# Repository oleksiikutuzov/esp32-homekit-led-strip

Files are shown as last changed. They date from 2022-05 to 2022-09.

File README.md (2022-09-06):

# esp32-homekit-led-strip
Native Apple HomeKit via an ESP32 for the NeoPixel LED Strip or any 5V LED Strip



Software is based on [HomeSpan](https://github.com/HomeSpan/HomeSpan) library. Supports RGB or RGBW Neopixel strips and optionally can act like a switch for any 5V electronics (Switch accessory in HomeKit can be shown as a Bulb, Socket or Fan).

_As usual, don't expect any warranties. I am just a hobbyist, not a professional. It works for me, but you take your own risk using it. I am not liable for any damage to your devices._

## Hardware

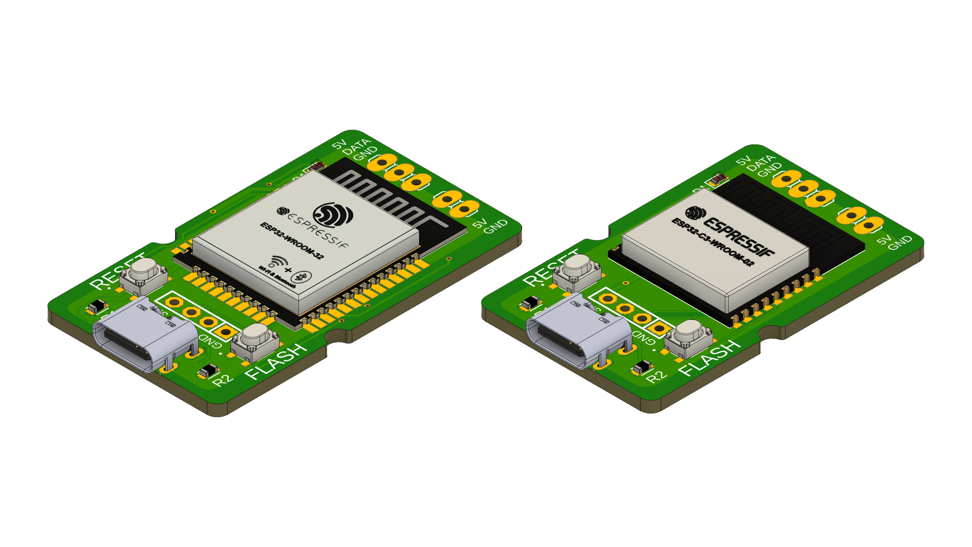
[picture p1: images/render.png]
render


Custom PCB is designed for the project. Currently for regular ESP32 board, however there are plans to do for ESP32-C3, which has smaller footprint.

## HomeKit functions

Device has three modes, which can be switched via the Eve app. As they are custim characteristics, they are not visible in the Home app:
* Manual Control (manually set one single color)
* Rainbow (the whole strip is changing colors)
* Color Wheel (strip has different colors "running" along)

Also in the Eve app you can set the number of LEDs in your strip (default is 90). After changing this characteristic, you need to restart the controller for changes to take effect. 

Characteristics values are saved to NVS, so they will be restored if device looses power. 

At the moment you can enable the Switch device in the sketch by defining the `RELAY` variable, but in the future this will implemented via custom characteristic as well to be able to enable it when device is running.

## Software

Here you can see, which pins are used and pre-defined in the firmware:
```c++
 *                ESP-WROOM-32 Utilized pins
 *              ╔═════════════════════════════╗
 *              ║┌─┬─┐  ┌──┐  ┌─┐             ║
 *              ║│ | └──┘  └──┘ |             ║
 *              ║│ |            |             ║
 *              ╠═════════════════════════════╣
 *          +++ ║GND                       GND║ +++
 *          +++ ║3.3V                     IO23║ USED_FOR_NOTHING
 *              ║                         IO22║
 *              ║IO36                      IO1║ TX
 *              ║IO39                      IO3║ RX
 *              ║IO34                     IO21║
 *              ║IO35                         ║ NC
 *      RED_LED ║IO32                     IO19║
 *              ║IO33                     IO18║ RELAY
 *              ║IO25                      IO5║
 *              ║IO26                     IO17║ NEOPIXEL
 *              ║IO27                     IO16║
 *              ║IO14                      IO4║
 *              ║IO12                      IO0║ +++, BUTTON
 *              ╚═════════════════════════════╝
```

The firmware can be built and flashed using the Arduino IDE.

For this, you will need to add ESP32 support to it.

Furthermore, you will also need to install the following libraries using the Library Manager:

* HomeSpan

And some libraries manually:

1. Go to this GitHub repo and download it as a ZIP - [AsyncElegantOTA](https://github.com/ayushsharma82/AsyncElegantOTA)
2. In Arduino IDE select "Sketch" -> "Include Library" and "Add .ZIP Library..." and select downloaded ZIP
3. Do previous steps to the following libraries: 
   * [ESPAsyncWebServer](https://github.com/me-no-dev/ESPAsyncWebServer)
   * [AsyncTCP](https://github.com/me-no-dev/AsyncTCP)
4. Download and open this repository in Arduino IDE (or VSCode with Arduino extension)
5. Set the upload speed to 115200
6. Build, flash, and you're done

Instead of Arduino IDE OTA, the webserver update was implemented. You can flash binary at `http://[DEVICE IP]/update`.
There is a reboot link. Opening `http://[DEVICE IP]/reboot` will force the device to reboot. 

The device can also be controlled by the FLASH button on the board. More on [HomeSpan docs](https://github.com/HomeSpan/HomeSpan/blob/master/docs/UserGuide.md)

## Connect to HomeKit

1. Plug your LED Controller to power.
2. Press the FLASH button until the LED starts blinking rapidly and release it. Now it is in the configuration mode (More on [HomeSpan docs](https://github.com/HomeSpan/HomeSpan/blob/master/docs/UserGuide.md)). Press it two more times until the LED starts blinking 3 times in a row. This means mode 3 is chosen. Hold the button for 3-4 seconds once again and the WiFi AP will be started.
3. Go to WiFi settings on your iPhone/iPad and connect to the "HomeSpan-Setup" WiFi network.
4. You will choose your WiFi network and set the setup code for the accessory. 
5. Go to your Home app and select "Add Accessory"
6. Select "More Options" and you should see your LED Controller there.

## References and sources

- @HomeSpan for ESP32 HomeKit firmware [GitHub link](https://github.com/HomeSpan/HomeSpan)

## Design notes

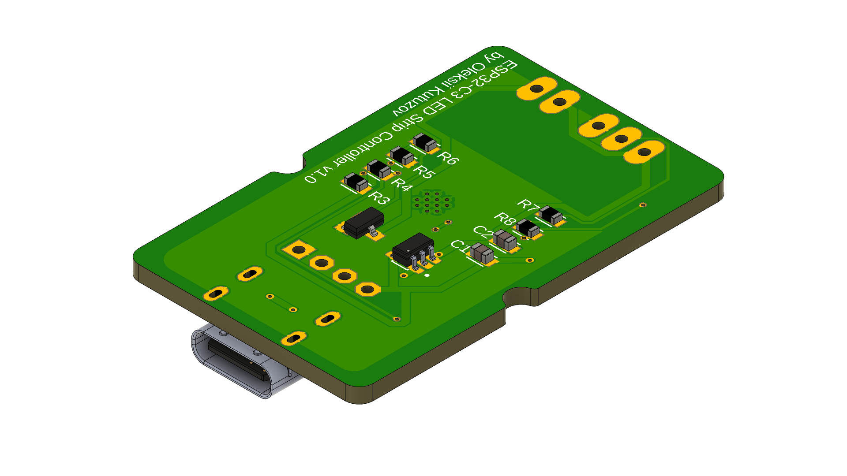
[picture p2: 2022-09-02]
PCB/ESP32-C3/ESP32-C3_v1.0_BOTTOM.png

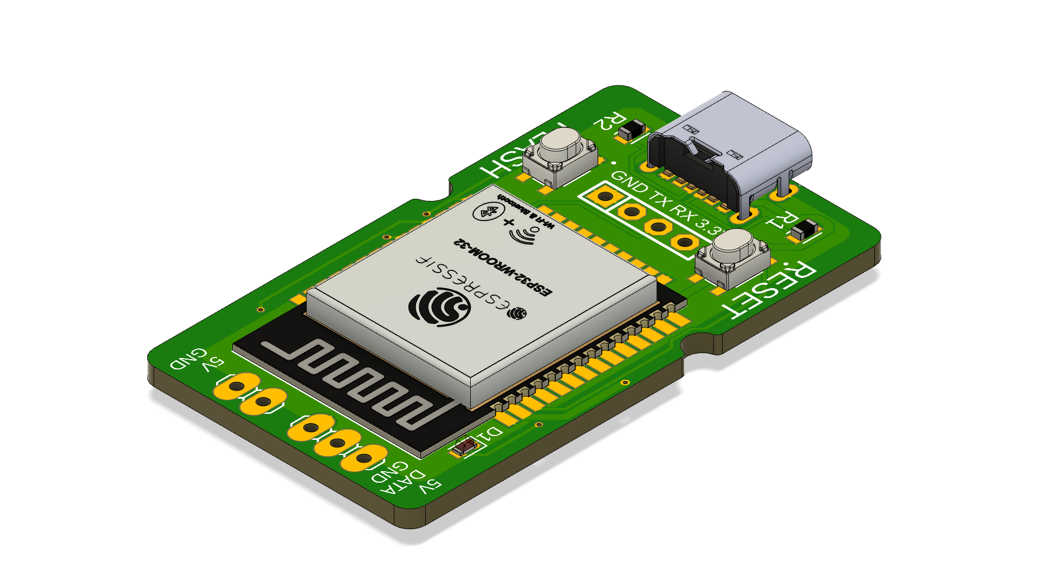
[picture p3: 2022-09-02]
PCB/ESP32/ESP32_v1.1_TOP.png

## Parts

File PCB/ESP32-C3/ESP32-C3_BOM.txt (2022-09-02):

Part Value                Device                   Package                     Description                                                                                                                     AVAILABILITY CATEGORY   
C1   10uF                 C_CHIP-0603(1608-METRIC) CAPC1608X85                 Capacitor - Generic                                                                                                                          Capacitor  
C2   10uF                 C_CHIP-0603(1608-METRIC) CAPC1608X85                 Capacitor - Generic                                                                                                                          Capacitor 
D1   LED                  CHIP-FLAT-R_0603-0.80MM  LEDC1608X80N_FLAT-R                                                                                                                                                      LED       
J1   USB4125-GF-A_REVA    USB4125-GF-A_REVA        GCT_USB4125-GF-A_REVA       USB 2.0 Type C Receptacle, Horizontal, SMT, For Power charging  Check prices                                                    Warning                
J2   F-1X04-SIP-100-40    F-1X04-SIP-100-40        SIP-100-04-40               FEMALE HEADER                                                                                                                                           
J3   PINHD-1X2            PINHD-1X2                1X02                        PIN HEADER                                                                                                                                   CONNECTOR  
LED1 PINHD-1X3            PINHD-1X3                1X03                        PIN HEADER                                                                                                                                   CONNECTOR  
Q1   NMOSFET              NMOSFET_SOT23-GSD        SOT23                       N-Channel MOSFET - Generic                                                                                                                   Transistor
R1   5.1k                 R_CHIP-0603(1608-METRIC) RESC1608X60                 Resistor Fixed - Generic                                                                                                                     Resistor  
R2   5.1k                 R_CHIP-0603(1608-METRIC) RESC1608X60                 Resistor Fixed - Generic                                                                                                                     Resistor  
R3   4.7K                 R_CHIP-0603(1608-METRIC) RESC1608X60                 Resistor Fixed - Generic                                                                                                                     Resistor  
R4   4.7K                 R_CHIP-0603(1608-METRIC) RESC1608X60                 Resistor Fixed - Generic                                                                                                                     Resistor  
R5   10k                  R_CHIP-0603(1608-METRIC) RESC1608X60                 Resistor Fixed - Generic                                                                                                                     Resistor  
R6   1k                   R_CHIP-0603(1608-METRIC) RESC1608X60                 Resistor Fixed - Generic                                                                                                                     Resistor  
R7   300-500 ohm          R_CHIP-0603(1608-METRIC) RESC1608X60                 Resistor Fixed - Generic                                                                                                                     Resistor  
R8   430                  R_CHIP-0603(1608-METRIC) RESC1608X60                 Resistor Fixed - Generic                                                                                                                     Resistor  
S1   SKRPACE010           SKRPACE010               SW_SKRPACE010               Switch Tactile N.O. SPST Button J-Bend 0.05A 16VDC 2.55N SMD Automotive T/R                                                                            
S2   SKRPACE010           SKRPACE010               SW_SKRPACE010               Switch Tactile N.O. SPST Button J-Bend 0.05A 16VDC 2.55N SMD Automotive T/R                                                                            
U1   AP2112K-3.3TRG1      AP2112K-3.3TRG1          SOT95P285X140-5N            AP2112 Series 0.6 A 3.3 V Fixed Output SMT LDO Linear Regulator - SOT23-5                                                                              
U2   ESP32-C3-WROOM-02-H4 ESP32-C3-WROOM-02-H4     MODULE_ESP32-C3-WROOM-02-H4 WiFi Modules (802.11) (Engineering Samples) SMD module, ESP32-C3, 4MB SPI flash, PCB antenna, -40 C +105 C   Check availability In Stock

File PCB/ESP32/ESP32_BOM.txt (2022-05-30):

Part Value             Device                   Package               Description                                                                               
C1   10uF              C_CHIP-0603(1608-METRIC) CAPC1608X85           Capacitor - Generic  (voltage converter)                                               
C2   10uF              C_CHIP-0603(1608-METRIC) CAPC1608X85           Capacitor - Generic  (voltage converter)                                                   
D1   LED               CHIP-FLAT-R_0603-0.80MM  LEDC1608X80N_FLAT-R                                                                                             
J1   USB4125-GF-A_REVA USB4125-GF-A_REVA        GCT_USB4125-GF-A_REVA USB 2.0 Type C Receptacle, Horizontal, SMT, For Power charging  Check prices Warning     
J2   F-1X04-SIP-100-40 F-1X04-SIP-100-40        SIP-100-04-40         FEMALE HEADER                                                                             
J3   PINHD-1X2         PINHD-1X2                1X02                  PIN HEADER                                                                                
LED1 PINHD-1X3         PINHD-1X3                1X03                  PIN HEADER                                                                                
Q1   NMOSFET           NMOSFET_SOT23            SOT23                 N-Channel MOSFET - Generic                                                                
R1   5.1k              R_CHIP-0603(1608-METRIC) RESC1608X60           Resistor Fixed - Generic                                                                  
R2   5.1k              R_CHIP-0603(1608-METRIC) RESC1608X60           Resistor Fixed - Generic                                                                  
R3   4.7K              R_CHIP-0603(1608-METRIC) RESC1608X60           Resistor Fixed - Generic                                                                  
R4   4.7K              R_CHIP-0603(1608-METRIC) RESC1608X60           Resistor Fixed - Generic                                                                  
R5   10k               R_CHIP-0603(1608-METRIC) RESC1608X60           Resistor Fixed - Generic                                                                  
R6   1k                R_CHIP-0603(1608-METRIC) RESC1608X60           Resistor Fixed - Generic                                                                  
R7   300-500 ohm       R_CHIP-0603(1608-METRIC) RESC1608X60           Resistor Fixed - Generic                                                                  
R8   430               R_CHIP-0603(1608-METRIC) RESC1608X60           Resistor Fixed - Generic                                                                  
S1   SKRPACE010        SKRPACE010               SW_SKRPACE010         Switch Tactile N.O. SPST Button J-Bend 0.05A 16VDC 2.55N SMD Automotive T/R              
S2   SKRPACE010        SKRPACE010               SW_SKRPACE010         Switch Tactile N.O. SPST Button J-Bend 0.05A 16VDC 2.55N SMD Automotive T/R           
U1   AP2112K-3.3TRG1   AP2112K-3.3TRG1          SOT95P285X140-5N      AP2112 Series 0.6 A 3.3 V Fixed Output SMT LDO Linear Regulator - SOT23-5                
U2   ESP32-WROOM       ESP32-WROOM              ESP32-WROOM

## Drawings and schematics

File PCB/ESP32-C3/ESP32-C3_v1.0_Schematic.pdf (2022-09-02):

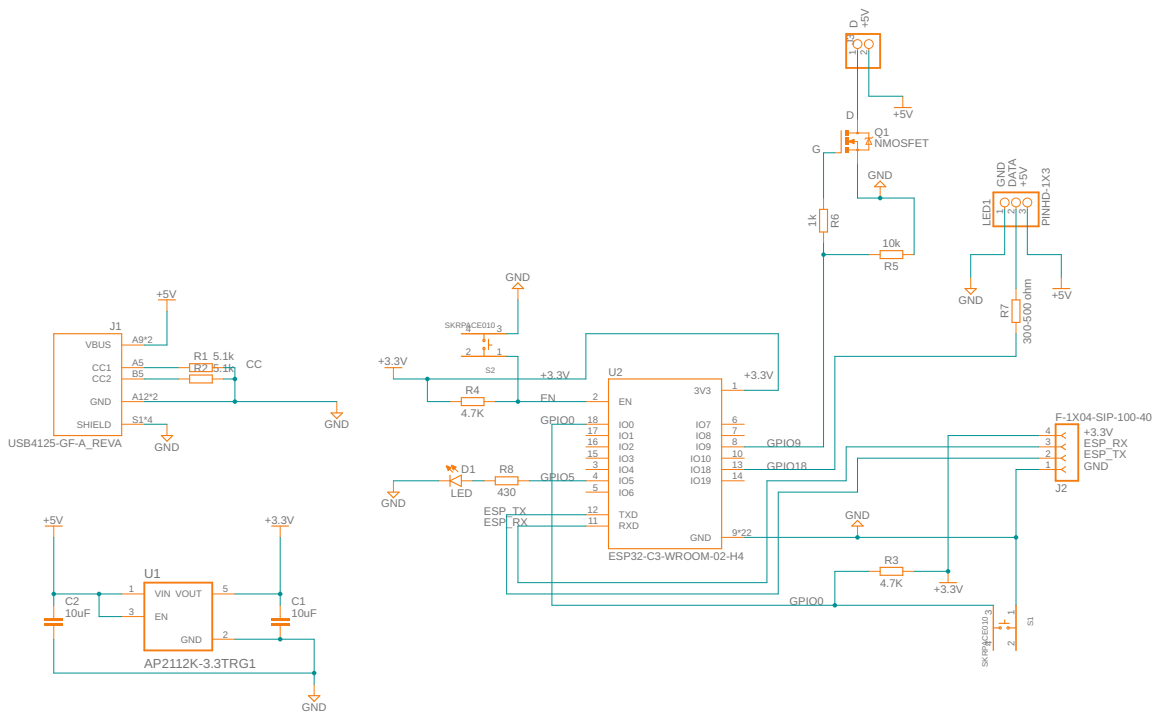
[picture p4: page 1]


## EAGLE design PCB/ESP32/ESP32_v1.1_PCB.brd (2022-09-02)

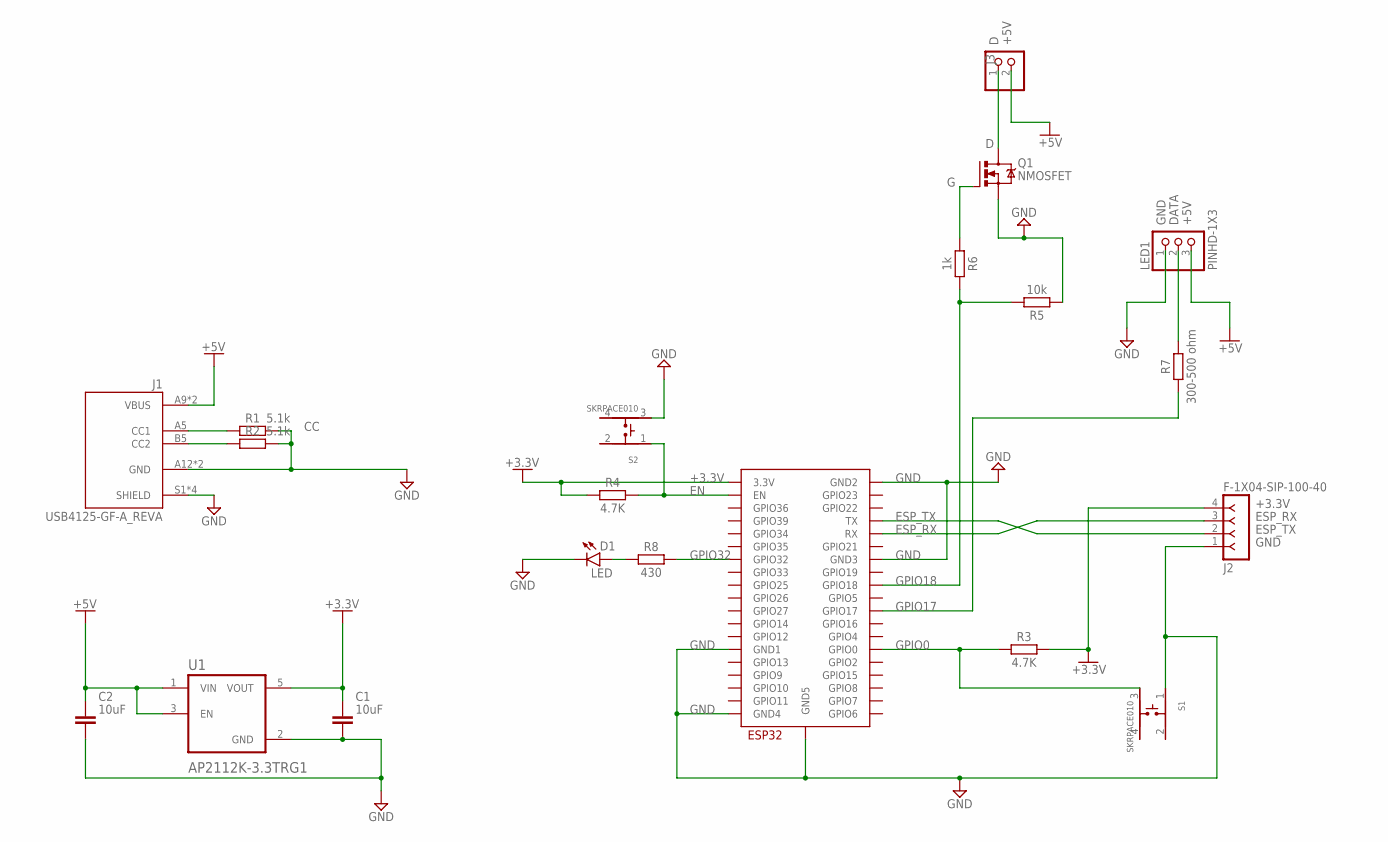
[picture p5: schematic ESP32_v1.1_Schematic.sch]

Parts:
C1, C2: 10uF; CAPC1608X85
D1: LED; LEDC1608X80N_FLAT-R
J1: USB4125-GF-A_REVA; GCT_USB4125-GF-A_REVA
J2: F-1X04-SIP-100-40; SIP-100-04-40
J3: PINHD-1X2; 1X02
LED1: PINHD-1X3; 1X03
Q1: NMOSFET; SOT23
R1, R2: 5.1k; RESC1608X60
R3, R4: 4.7K; RESC1608X60
R5: 10k; RESC1608X60
R6: 1k; RESC1608X60
R7: 300-500 ohm; RESC1608X60
R8: 430; RESC1608X60
S1, S2: SKRPACE010; SW_SKRPACE010
U1: AP2112K-3.3TRG1; SOT95P285X140-5N
U2: ESP32-WROOM

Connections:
+3.3V: C1.1, J2.4, R3.2, R4.1, U1.5 (VOUT), U2.3V3 (3.3V)
+5V: C2.1, J1.A9 (VBUS), J1.B9 (VBUS), J3.2, LED1.3, U1.1 (VIN), U1.3 (EN)
CC: J1.A5 (CC1), R1.1
D: J3.1, Q1.3 (D)
DATA: LED1.2, R7.2
EN: R4.2, S2.1, U2.EN
ESP_RX: J2.3, U2.RX
ESP_TX: J2.2, U2.TX
G: Q1.1 (G), R6.1
GND: C1.2, C2.2, D1.C, J1.A12 (GND), J1.B12 (GND), J1.S1 (SHIELD), J1.S2 (SHIELD), J1.S3 (SHIELD), J1.S4 (SHIELD), J2.1, LED1.1, Q1.2 (S), R1.2, R2.2, R5.1, S1.1, S2.3, U1.2 (GND), U2.GND1, U2.GND2, U2.GND3, U2.GND4, U2.GND5
GPIO0: R3.1, S1.3, U2.IO0 (GPIO0)
GPIO17: R7.1, U2.IO17 (GPIO17)
GPIO18: R5.2, R6.2, U2.IO18 (GPIO18)
GPIO32: R8.2, U2.IO32 (GPIO32)
LED: D1.A, R8.1
unnamed: J1.B5 (CC2), R2.1

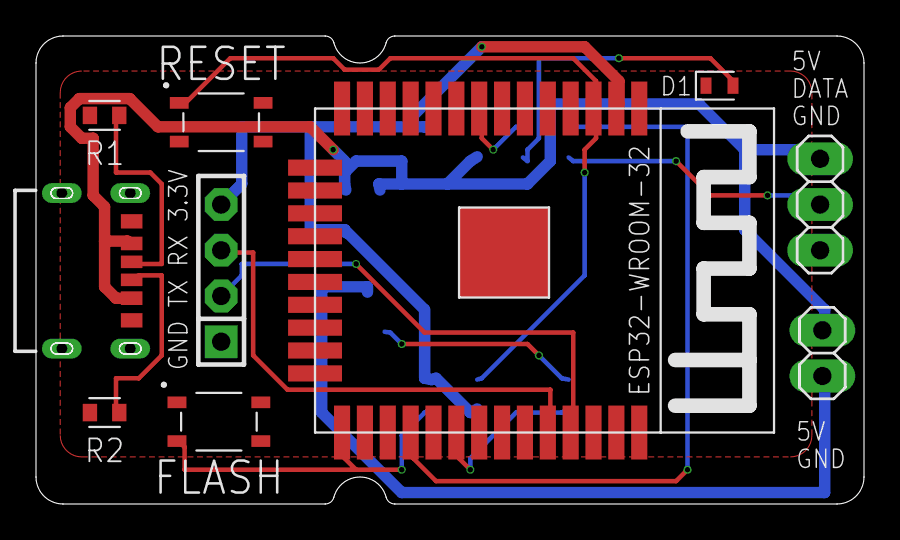
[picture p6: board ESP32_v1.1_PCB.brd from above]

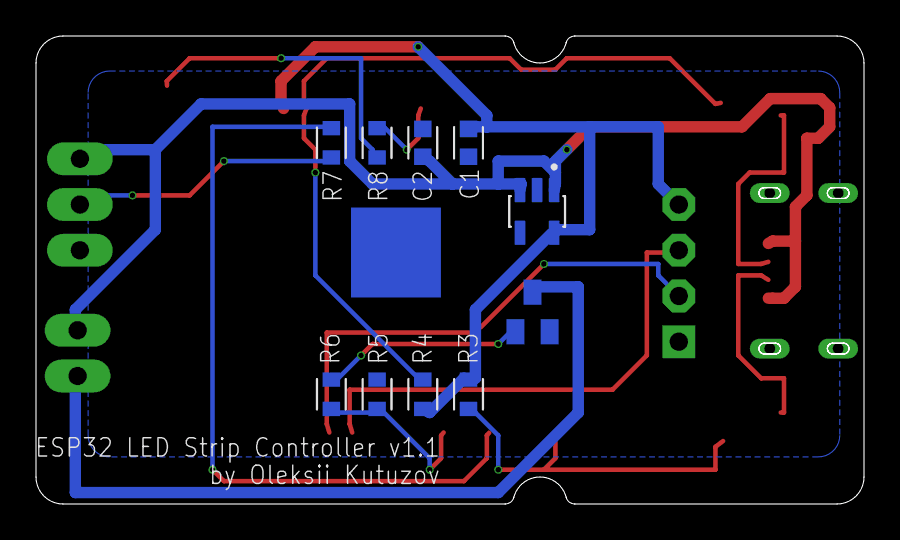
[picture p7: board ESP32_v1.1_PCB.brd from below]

Board: 2 copper layers, 46.0 x 26.0 mm, 20 parts (10 on the bottom side), 16 nets.

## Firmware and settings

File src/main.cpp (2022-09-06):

/*********************************************************************************
 *  MIT License
 *
 *  Copyright (c) 2022 Gregg E. Berman
 *
 *  https://github.com/HomeSpan/HomeSpan
 *
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
 ********************************************************************************/

/*
 *                ESP-WROOM-32 Utilized pins
 *              ╔═════════════════════════════╗
 *              ║┌─┬─┐  ┌──┐  ┌─┐             ║
 *              ║│ | └──┘  └──┘ |             ║
 *              ║│ |            |             ║
 *              ╠═════════════════════════════╣
 *          +++ ║GND                       GND║ +++
 *          +++ ║3.3V                     IO23║ USED_FOR_NOTHING
 *              ║                         IO22║
 *              ║IO36                      IO1║ TX
 *              ║IO39                      IO3║ RX
 *              ║IO34                     IO21║
 *              ║IO35                         ║ NC
 *      RED_LED ║IO32                     IO19║
 *              ║IO33                     IO18║ RELAY
 *              ║IO25                      IO5║
 *              ║IO26                     IO17║ NEOPIXEL
 *              ║IO27                     IO16║
 *              ║IO14                      IO4║
 *              ║IO12                      IO0║ +++, BUTTON
 *              ╚═════════════════════════════╝
 */

float angle		  = 0;
long  count_wheel = 0;

#define MAX_LEDS 120
#define MAXHUE	 360
#define REQUIRED VERSION(1, 6, 0)

#include "HomeSpan.h"
#include "extras/Pixel.h" // include the HomeSpan Pixel class
#include <WiFiClient.h>
#include <WebServer.h>
#include <ElegantOTA.h>
#include "OTA.hpp"

uint16_t relay;

char sNumber[18] = "11:11:11:11:11:11";

#if defined(CONFIG_IDF_TARGET_ESP32)

#define NEOPIXEL_RGBW_PIN 17

#elif defined(CONFIG_IDF_TARGET_ESP32S2)

#define NEOPIXEL_RGBW_PIN 38

#elif defined(CONFIG_IDF_TARGET_ESP32C3)

#define NEOPIXEL_RGBW_PIN 2

#endif

void addSwitch();
void setupWeb();

// clang-format off
CUSTOM_CHAR(Selector, 00000001-0001-0001-0001-46637266EA00, PR + PW + EV, UINT8, 1, 1, 3, false); // create Custom Characteristic to "select" special effects via Eve App
CUSTOM_CHAR(NumLeds, 00000002-0001-0001-0001-46637266EA00, PR + PW + EV, UINT8, 90, 1, MAX_LEDS, false);
CUSTOM_CHAR(RelayEnabled, 00000003-0001-0001-0001-46637266EA00, PR + PW + EV, BOOL, 0, 0, 1, false);
CUSTOM_CHAR(AnimSpeed, 00000004-0001-0001-0001-46637266EA00, PR + PW + EV, UINT8, 1, 1, 10, false);
CUSTOM_CHAR(AutoUpdate, 00000005-0001-0001-0001-46637266EA00, PR + PW + EV, BOOL, 0, 0, 1, false);
CUSTOM_CHAR_STRING(IPAddress, 00000006-0001-0001-0001-46637266EA00, PR + EV, "");
// clang-format on

// declare function
int *Wheel(byte WheelPos);
///////////////////////////////
WebServer server(80);
struct Pixel_Strand : Service::LightBulb { // Addressable RGBW Pixel Strand of nPixel Pixels

	struct SpecialEffect {
		Pixel_Strand *px;
		const char	 *name;

		SpecialEffect(Pixel_Strand *px, const char *name) {
			this->px   = px;
			this->name = name;
			Serial.printf("Adding Effect %d: %s\n", px->Effects.size() + 1, name);
		}

		virtual void	 init() {}
		virtual uint32_t update() { return (60000); }
		virtual int		 requiredBuffer() { return (0); }
	};

	Characteristic::On			 power{0, true};
	Characteristic::Hue			 H{0, true};
	Characteristic::Saturation	 S{100, true};
	Characteristic::Brightness	 V{100, true};
	Characteristic::Selector	 effect{1, true};
	Characteristic::NumLeds		 num_leds{90, true};
	Characteristic::RelayEnabled relay_enabled{false, true};
	Characteristic::AnimSpeed	 anim_speed{1, true};
	Characteristic::AutoUpdate	 auto_update{false, true};
	Characteristic::IPAddress	 ip_address{"0.0.0.0"};

	vector<SpecialEffect *>
		Effects;

	Pixel		 *pixel;
	int			  nPixels;
	Pixel::Color *colors;
	uint32_t	  alarmTime;

	Pixel_Strand(int pin) : Service::LightBulb() {

		pixel = new Pixel(pin, false); // creates RGBW pixel LED on specified pin using default timing parameters suitable for most SK68xx LEDs

		Effects.push_back(new ManualControl(this));
		Effects.push_back(new Rainbow(this));
		Effects.push_back(new Colorwheel(this));

		effect.setUnit(""); // configures custom "Selector" characteristic for use with Eve HomeKit
		effect.setDescription("Color Effect");
		effect.setRange(1, Effects.size(), 1);

		num_leds.setUnit(""); // configures custom "Selector" characteristic for use with Eve HomeKit
		num_leds.setDescription("Number of LEDs");
		num_leds.setRange(1, MAX_LEDS, 1);

		anim_speed.setUnit(""); // configures custom "Selector" characteristic for use with Eve HomeKit
		anim_speed.setDescription("Animation Speed");
		anim_speed.setRange(1, 10, 1);

		relay_enabled.setDescription("Switch Enabled");

		auto_update.setDescription("Auto OTA Update");

		ip_address.setDescription("IP Address");

		V.setRange(5, 100, 1); // sets the range of the Brightness to be from a min of 5%, to a max of 100%, in steps of 1%

		this->nPixels = num_leds.getNewVal(); // store number of Pixels in Strand

		int bufSize = 0;

		for (int i = 0; i < Effects.size(); i++)
			bufSize = Effects[i]->requiredBuffer() > bufSize ? Effects[i]->requiredBuffer() : bufSize;

		colors = (Pixel::Color *)calloc(bufSize, sizeof(Pixel::Color)); // storage for dynamic pixel pattern

		Serial.printf("\nConfigured Pixel_Strand on pin %d with %d pixels and %d effects.  Color buffer = %d pixels\n\n", pin, this->nPixels, Effects.size(), bufSize);

		update();
	}

	boolean update() override {

		if (!power.getNewVal()) {
			pixel->set(Pixel::Color().RGB(0, 0, 0, 0), this->nPixels);
		} else {
			Effects[effect.getNewVal() - 1]->init();
			alarmTime = millis() + Effects[effect.getNewVal() - 1]->update();
			if (effect.updated())
				Serial.printf("Effect changed to: %s\n", Effects[effect.getNewVal() - 1]->name);
		}
		if (relay_enabled.updated()) {
			int relay_status = relay_enabled.getNewVal();
			if (relay_enabled.getNewVal()) {
				LOG0("Relay Enabled\n");
				addSwitch();
				homeSpan.updateDatabase();
				LOG0("Accessories Database updated.  New configuration number broadcasted...\n");
			} else {
				LOG0("Relay Disabled\n");
				homeSpan.deleteAccessory(2);
				homeSpan.updateDatabase();
				LOG0("Nothing to update - no changes were made!\n");
			}
		}

		return (true);
	}

	void loop() override {

		if (millis() > alarmTime && power.getVal())
			alarmTime = millis() + Effects[effect.getNewVal() - 1]->update();

		if (auto_update.timeVal() > INTERVAL) {
			if (auto_update.getVal()) {
				if (FirmwareVersionCheck()) {
					firmwareUpdate();
				}
			}
		}
	}

	//////////////

	struct ManualControl : SpecialEffect {

		ManualControl(Pixel_Strand *px) : SpecialEffect{px, "Manual Control"} {}

		void init() override { px->pixel->set(Pixel::Color().HSV(px->H.getNewVal<float>(), px->S.getNewVal<float>(), px->V.getNewVal<float>()), px->nPixels); }
	};

	//////////////
	struct Rainbow : SpecialEffect {

		int8_t *dir;

		Rainbow(Pixel_Strand *px) : SpecialEffect{px, "Rainbow"} {
			dir = (int8_t *)calloc(px->nPixels, sizeof(int8_t));
		}

		void init() override {
			for (int i = 0; i < px->nPixels; i++) {
				px->colors[i].RGB(0, 0, 0, 0);
				dir[i] = 0;
			}
		}

		uint32_t update() override {
			float value = px->V.getNewVal<float>();
			for (int i = 0; i < px->nPixels; i++) {
				px->colors[i] = Pixel::Color().HSV(angle, 100, value);
			}
			px->pixel->set(px->colors, px->nPixels);
			if (angle++ == 360) angle = 0;
			int speed = px->anim_speed.getVal();
			return (200 / speed);
		}

		int requiredBuffer() override { return (px->nPixels); }
	};

	///////////////////////////////
	struct Colorwheel : SpecialEffect {

		int8_t *dir;

		Colorwheel(Pixel_Strand *px) : SpecialEffect{px, "Colorwheel"} {
			dir = (int8_t *)calloc(px->nPixels, sizeof(int8_t));
		}

		void init() override {
			for (int i = 0; i < px->nPixels; i++) {
				px->colors[i].RGB(0, 0, 0, 0);
				dir[i] = 0;
			}
		}

		uint32_t update() override {
			float value = px->V.getNewVal<float>();
			for (int i = 0; i < px->nPixels; i++) {
				int h		  = (i * (MAXHUE / px->nPixels) + count_wheel) % MAXHUE;
				px->colors[i] = Pixel::Color().HSV(h, 100, value);
			}
			px->pixel->set(px->colors, px->nPixels);
			if (count_wheel++ == MAXHUE) count_wheel = 0;
			int speed = px->anim_speed.getVal();
			return (200 / speed);
		}

		int requiredBuffer() override { return (px->nPixels); }
	};
	///////////////////////////////
};

struct DEV_Switch : Service::Switch {

	int					ledPin; // relay pin
	SpanCharacteristic *power;

	// Constructor
	DEV_Switch(int ledPin) : Service::Switch() {
		power		 = new Characteristic::On(0, true);
		this->ledPin = ledPin;
		pinMode(ledPin, OUTPUT);

		digitalWrite(ledPin, power->getVal());
	}

	// Override update method
	boolean update() {
		digitalWrite(ledPin, power->getNewVal());

		return (true);
	}
};

///////////////////////////////

Pixel_Strand *STRIP;

void setup() {

	Serial.begin(115200);

	Serial.print("Active firmware version: ");
	Serial.println(FirmwareVer);

	String	   temp			  = FW_VERSION;
	const char compile_date[] = __DATE__ " " __TIME__;
	char	  *fw_ver		  = new char[temp.length() + 30];
	strcpy(fw_ver, temp.c_str());
	strcat(fw_ver, " (");
	strcat(fw_ver, compile_date);
	strcat(fw_ver, ")");

	for (int i = 0; i < 17; ++i) // we will iterate through each character in WiFi.macAddress() and copy it to the global char sNumber[]
	{
		sNumber[i] = WiFi.macAddress()[i];
	}
	sNumber[17] = '\0'; // the last charater needs to be a null

	homeSpan.setLogLevel(0);										// set log level to 0 (no logs)
	homeSpan.setStatusPin(32);										// set the status pin to GPIO32
	homeSpan.setStatusAutoOff(10);									// disable led after 10 seconds
	homeSpan.setWifiCallback(setupWeb);								// Set the callback function for wifi events
	homeSpan.reserveSocketConnections(5);							// reserve 5 socket connections for Web Server
	homeSpan.setControlPin(0);										// set the control pin to GPIO0
	homeSpan.setPortNum(88);										// set the port number to 81
	homeSpan.enableAutoStartAP();									// enable auto start of AP
	homeSpan.enableWebLog(10, "pool.ntp.org", "UTC-2:00", "myLog"); // enable Web Log
	homeSpan.setSketchVersion(fw_ver);

	homeSpan.begin(Category::Lighting, "Holiday Lights");

	new SpanAccessory(1);
	new Service::AccessoryInformation();
	new Characteristic::Name("Holiday Lights");
	new Characteristic::Manufacturer("HomeSpan");
	new Characteristic::SerialNumber(sNumber);
	new Characteristic::Model("NeoPixel RGB LEDs");
	new Characteristic::FirmwareRevision(temp.c_str());
	new Characteristic::Identify();

	new Service::HAPProtocolInformation();
	new Characteristic::Version("1.1.0");

	STRIP = new Pixel_Strand(NEOPIXEL_RGBW_PIN);

	if (STRIP->relay_enabled.getVal()) {
		addSwitch();
	}
}

///////////////////////////////

void loop() {
	homeSpan.poll();
	server.handleClient();
	// repeatedCall();
}

///////////////////////////////

void setupWeb() {

	server.on("/metrics", HTTP_GET, []() {
		double uptime		= esp_timer_get_time() / (6 * 10e6);
		double heap			= esp_get_free_heap_size();
		String uptimeMetric = "# HELP uptime LED Strip uptime\nhomekit_uptime{device=\"led_strip\",location=\"home\"} " + String(int(uptime));
		String heapMetric	= "# HELP heap Available heap memory\nhomekit_heap{device=\"led_strip\",location=\"home\"} " + String(int(heap));

		Serial.println(uptimeMetric);
		Serial.println(heapMetric);
		server.send(200, "text/plain", uptimeMetric + "\n" + heapMetric);
	});

	server.on("/reboot", HTTP_GET, []() {
		String content = "<html><body>Rebooting!  Will return to configuration page in 10 seconds.<br><br>";
		content += "<meta http-equiv = \"refresh\" content = \"10; url = /\" />";
		server.send(200, "text/html", content);

		ESP.restart();
	});

	STRIP->ip_address.setString(WiFi.localIP().toString().c_str());
	ElegantOTA.begin(&server); // Start ElegantOTA
	server.begin();
	LOG1("HTTP server started");
} // setupWeb

void addSwitch() {

	LOG0("Adding Accessory: Switch\n");

	new SpanAccessory(2);
	new Service::AccessoryInformation();
	new Characteristic::Name("Switch");
	new Characteristic::Identify();
	new DEV_Switch(18);
}

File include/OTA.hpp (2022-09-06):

#include <WiFi.h>
#include <HTTPClient.h>
#include <HTTPUpdate.h>
#include <WiFiClientSecure.h>
#include "cert.hpp"
#include <HomeSpan.h>

// 1 - ESP32, 2 - ESP32-C3
#ifndef BOARD
#define BOARD 1
#endif

#define URL_fw_Version "https://raw.githubusercontent.com/oleksiikutuzov/esp32-homekit-led-strip/main/bin_version.txt"

#if BOARD == 1
#define URL_fw_Bin "https://raw.githubusercontent.com/oleksiikutuzov/esp32-homekit-led-strip/main/esp32_led_strip.bin"
#elif BOARD == 2
#define URL_fw_Bin "https://raw.githubusercontent.com/oleksiikutuzov/esp32-homekit-led-strip/main/esp32c3_led_strip.bin"
#endif

#define FW_VERSION "1.3.6"

String FirmwareVer = {
	FW_VERSION};

void firmwareUpdate();
int	 FirmwareVersionCheck();

unsigned long previousMillis = 0; // will store last time LED was updated
#define INTERVAL 60 * 60 * 1000	  // 1 hour in ms

// void repeatedCall() {
// 	static int	  num			= 0;
// 	unsigned long currentMillis = millis();

// 	if ((currentMillis - previousMillis) >= interval) {
// 		// save the last time you blinked the LED
// 		previousMillis = currentMillis;
// 		if (FirmwareVersionCheck()) {
// 			firmwareUpdate();
// 		}
// 	}
// }

void firmwareUpdate(void) {
	WiFiClientSecure client;
	client.setCACert(rootCACertificate);
	t_httpUpdate_return ret = httpUpdate.update(client, URL_fw_Bin);

	switch (ret) {
	case HTTP_UPDATE_FAILED:
		LOG1("HTTP_UPDATE_FAILED Error (%d): %s\n", httpUpdate.getLastError(), httpUpdate.getLastErrorString().c_str());
		break;

	case HTTP_UPDATE_NO_UPDATES:
		LOG1("HTTP_UPDATE_NO_UPDATES");
		break;

	case HTTP_UPDATE_OK:
		LOG1("HTTP_UPDATE_OK");
		break;
	}
}

int FirmwareVersionCheck(void) {
	String payload;
	int	   httpCode;
	String fwurl = "";
	fwurl += URL_fw_Version;
	fwurl += "?";
	fwurl += String(rand());
	Serial.println(fwurl);
	WiFiClientSecure *client = new WiFiClientSecure;

	if (client) {
		client->setCACert(rootCACertificate);

		// Add a scoping block for HTTPClient https to make sure it is destroyed before WiFiClientSecure *client is
		HTTPClient https;

		if (https.begin(*client, fwurl)) { // HTTPS
			Serial.print("[HTTPS] GET...\n");
			// start connection and send HTTP header
			delay(100);
			httpCode = https.GET();
			delay(100);
			if (httpCode == HTTP_CODE_OK) // if version received
			{
				payload = https.getString(); // save received version
			} else {
				Serial.print("error in downloading version file:");
				Serial.println(httpCode);
			}
			https.end();
		}
		delete client;
	}

	if (httpCode == HTTP_CODE_OK) // if version received
	{
		payload.trim();
		if (payload.equals(FirmwareVer)) {
			Serial.printf("\nDevice already on latest firmware version:%s\n", FirmwareVer);
			return 0;
		} else {
			Serial.println(payload);
			Serial.println("New firmware detected");
			return 1;
		}
	}
	return 0;
}

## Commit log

2022-04-26 Add basic led strip code
2022-05-07 Reserve 5 socket connections and add comments
2022-05-17 Redo rainbow wheel animation, schematic adjustment
2022-05-17 Add hardware files
    [PCB_v6.brd, Schematic_v7.sch]
2022-05-17 Add Switch accessory for relay
2022-05-24 Cleanup, enable/disable relay in code
2022-05-26 Add custom characteristic of setting LEDs number in eve app
2022-05-30 Prepare to dynamic add device function in HomeSpan
2022-05-30 Upload ESP32-C3 hardware files
    [ESP32-C3_PCB_v5.brd, ESP32-C3_Schematic_v1.0_v3.sch, ESP32_PCB_v12.brd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]
2022-05-31 Organize Hardware files
    [ESP32-C3_v1.0_PCB.brd, ESP32-C3_v1.0_Schematic.sch, ESP32_v1.1_PCB.brd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]
2022-07-12 Add dynamic enabling of the switch accessory
2022-07-14 Saving switch status to NVS
2022-08-09 Switch from ESPAsyncWebServer to WebServer
2022-08-17 Fix to animation, required HomeSpan version bump
    [led_strip.ino]
2022-09-03 Read switch status from characteristic
2022-09-06 Update (#13)
    * Switch to PlatformIO
2022-09-06 Add IP address and OTA Update switch Characteristics (#15)
    * Add Auto Update Characteristic
    * Show IP Address as Characteristic
2022-09-06 Fix update loop logic
    [main.cpp]

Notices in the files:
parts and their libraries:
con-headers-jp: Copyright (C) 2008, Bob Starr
